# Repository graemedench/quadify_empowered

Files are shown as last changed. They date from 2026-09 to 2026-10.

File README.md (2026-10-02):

# Quadify Empowered

Quadify Empowered is a **post-install enhancement pack** for [Sable](https://github.com/theshepherdmatt/sable) on Volumio. It does not include, replace, or redistribute Sable itself.

## Reversible FM4 conversion

This build is designed to leave the FM4 chassis capable of being returned to its
original FM4 condition. The included mounting and rear-panel parts use existing
openings and fixing points: there is no chassis drilling or cutting. Keep the
original hardware and fasteners with the unit so the conversion can be reversed.

Any work around the original IEC/power hardware must be carried out with the
unit fully disconnected from mains power. Have a suitably competent person make
safe any original mains wiring before removing its outlet or inlet hardware.

## Personal use and original rights

Quadify Empowered is provided for **personal, non-commercial use**. It must not be sold, resold, or commercially redistributed by anyone other than the original Quadify publisher. The original Quadify publisher is expressly permitted to use, distribute, and sell these files commercially. All rights in the original Quadify project and its materials remain with the original Quadify creator and publisher; all rights in Sable remain with its publisher. This enhancement pack does not grant commercial rights in either original project to any other party.

## FM4 button print pack

[`FM4 Button Print Pack`](FM4%20Button%20Print%20Pack/) contains the matching printable button-cap files: an all-variants 3MF plate, individual two-colour FDM parts, editable blank-cap source, and one-piece single-colour resin files with 1 mm raised icons (including a plain resin blank cap). See its read-me for the recommended print workflow.

Install standard Volumio and Sable first. This pack adds reliable OLED/boot feedback, the looping front-panel LED startup pattern, display and audio-performance refinements, improved TIDAL/Sable Radio navigation, configurable radio/TIDAL shortcut buttons, IR support, networking tools, graceful shutdown, and a modern low-overhead display mode.

## Install

This release is verified against Sable commit
`3670e503db8124de5890a6df1dc1b68b95d392a6`. For a repeatable clean build:

```bash
git clone https://github.com/theshepherdmatt/sable.git /home/volumio/sable
cd /home/volumio/sable
git checkout 3670e503db8124de5890a6df1dc1b68b95d392a6
sudo bash install.sh
```

Then install this enhancement pack:

```bash
git clone https://github.com/graemedench/quadify_empowered.git /home/volumio/quadify_empowered
cd /home/volumio/quadify_empowered
sudo ./install.sh
```

The installer checks the Sable revision before it applies anything. If it is not the verified revision, it stops with no changes. For a deliberately attempted newer-version install, take a backup first and use `--force`; it then asks Git to perform a three-way merge and stops on a conflict rather than overwriting code.

## Current front-panel additions

- Button 1: tap play/pause; hold gives the quiet five-minute soft-stop state.
- Button 2 cycles Play Single, Play All, Repeat Single, Repeat All and Shuffle.
- Button 8: tap saves the current item to the TIDAL **Quadify** playlist; hold
  opens Save Shortcut. Press 5, 6 or 7, choose short/long with the encoder,
  then push the encoder to save the current radio/TIDAL source.
- Settings → Shortcuts restores the 5–7 defaults for the selected profile.
- A long encoder press returns directly to Now Playing from any menu/browse depth.
- The panel menu provides display, output, network/IP and emergency Wi-Fi setup.

## CD ripping and library tools

Audio CD offers **Rip HQ** (lossless FLAC) and **Rip MP3** (320kbps), with a choice of internal storage or a mounted USB drive. This uses `cdparanoia`, `cd-discid`, and `ffmpeg` already available on the development Volumio image; other installations need these tools available. Rips are saved under `CD Rips/<artist>/<album>` in a unique folder.

The progress bar follows each track through reading and encoding, alongside a track counter. **Cancel** keeps completed songs; **Exit and continue** returns to the panel while ripping continues. Volumio's library is refreshed after completion or cancellation.

**Settings > Music Library** offers **Refresh now** and automatic refresh: Off, every 15 minutes, or hourly. Automatic refresh defaults to Off on a fresh installation and waits while a CD rip is active. Enable it to pick up files copied over the network.

**Settings > Storage** lists internal storage and mounted USB/network drives with free space. Select a drive for free/total capacity; reopen the list to refresh it.

## Output-menu presets

The default **general** menu detects usable Volumio outputs, hides HDMI, shows the built-in headphone output as variable-volume, and lists external outputs by their detected name.

Graeme's personal menu is restored with:

```bash
sudo ./install.sh --graeme
```

| Menu item | Hardware mapping |
| --- | --- |
| Lineout Fixed | Graeme's SMSL USB DAC, fixed volume |
| Lineout Variable | Graeme's SMSL USB DAC, software volume starting at 50% |
| Headphone Variable | Raspberry Pi built-in Audio Jack, software volume starting at 50% |

No music-service credentials or personal Volumio login details are included.

## Graeme hardware preset

`--graeme` also restores this Pi-specific configuration and backs up `/boot/userconfig.txt` first:

| Function | Configuration |
| --- | --- |
| OLED / panel SPI | `dtparam=spi=on` |
| IR receiver | HS0038 output on BCM GPIO27; 3.3 V and GND; Apple Aluminium Remote profile |
| IR device | `/dev/lirc1` |
| Shutdown button | BCM GPIO21, active-low, controlled by Sable |
| Button 8 | Save current track to Volumio's local `Quadify` playlist |

Reboot after `--graeme` so the IR overlay becomes active. The panel and GPIO wiring must match this profile.

## Updates

```bash
cd /home/volumio/quadify_empowered
git pull
sudo ./install.sh --graeme   # omit the switch for general mode
```

Update standard Sable separately using its own instructions. This remains an add-on, preserving the original project and its licensing.
## Optional playlist backup

To back up the local Volumio `Quadify` playlist (and a clickable, artwork-enabled TIDAL-links page) to your own Windows/NAS SMB share, run:

```bash
cd /home/volumio/quadify_empowered
sudo ./setup-playlist-backup.sh
```

It asks for the server, share, username and password **on the Pi**. None of these values are stored in Git. The credentials are saved only on that Pi in a root-only file. Backups run after every boot and every Sunday at 03:15, retaining `latest` plus three rotating numbered copies.

## Quick Back navigation

Every Settings submenu and music-browsing list ends with **Back**. Select it to return immediately; there is no need to wait for the automatic timeout.

## Shutdown from the panel

At the bottom of **Settings**, choose **Shutdown**, then **Confirm Shutdown**. This uses Sable's graceful shutdown sequence; it stops playback cleanly and turns off the display before power-off.

## Network menu

**Settings → Network** shows the active connection type and network name, for example Wi-Fi: MyNetwork, and can display its current IP address. It also includes an emergency Wi-Fi setup flow: scan for a network, select its SSID, then use the panel control to select password characters. The current password is visible only during entry; JOIN, CANCEL, and DELETE are the first picker options. Joining is passed to Volumio's own network controller, so it remains responsible for saved Wi-Fi settings.

## FM4 wiring diagram

The labelled build diagram is available at [docs/FM4-WIRING-DIAGRAM.svg](docs/FM4-WIRING-DIAGRAM.svg). It records the live FM4 GPIO, I²C, SPI, IR, rotary and shutdown-switch wiring.

The [FM4 build notes](docs/FM4-BUILD-NOTES.md) document the LED-8/IR receiver
conversion and link the included mounting-part STLs.

## Other FM4 printed parts

This repository currently includes the matching button-cap print pack, the
front-panel mounting parts (screen holder, rotary bracket and long knob
extender), and the reversible rear Ethernet-jack panel.

My FM4 build also has additional rear/enclosure pieces, and a cut-out template
for replacing the original PCB. These parts are intentionally **not included
yet** while their fit and final revision are being kept separate from the
current release. A USB-A+C rear-panel option is also planned; it will use the
existing IEC opening and have an optional backing plate to cover the original
power text, again without drilling. These will be added as and when.

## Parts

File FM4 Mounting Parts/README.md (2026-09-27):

# FM4 mounting parts

These are the current printable mounting STL files used on Graeme's FM4.

- `Screen Holder/FM4 Screen Holder V1.stl` — holds the SSD1322 display.
- `Rotary Bracket/FM4 Rotary Knob Bracket V4.stl` — mounts the rotary encoder.
- `Knob Extender/FM4 Knob Extender Long V6.stl` — extends the encoder shaft to
  the front knob.
- [`Rear Network Jack`](Rear%20Network%20Jack/) — a no-drill panel that uses
  the original rear IEC / POWER OUT opening for a panel-mount Ethernet extension.

The Ethernet panel and its fitting photos are documented in its own folder.
Other rear/enclosure parts are still being kept separate while their fit is
finalised.

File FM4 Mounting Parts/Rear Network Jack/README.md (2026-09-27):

# FM4 rear Ethernet jack panel

This STL replaces the original rear IEC / **POWER OUT** outlet with an RJ45
Ethernet extension mounted behind a printed panel. It is a reversible,
no-drill conversion: the panel uses the original rectangular opening and its
existing top and bottom fixing points.

## Included files

- `FM4 Rear Network Jack Panel.stl` — printable adaptor panel.
- `Photo - original IEC outlet.jpg` — the original outlet before removal.
- `Photo - fitted Ethernet panel.jpg` — the fitted RJ45 panel.

## Build reference

**Original IEC / POWER OUT outlet**

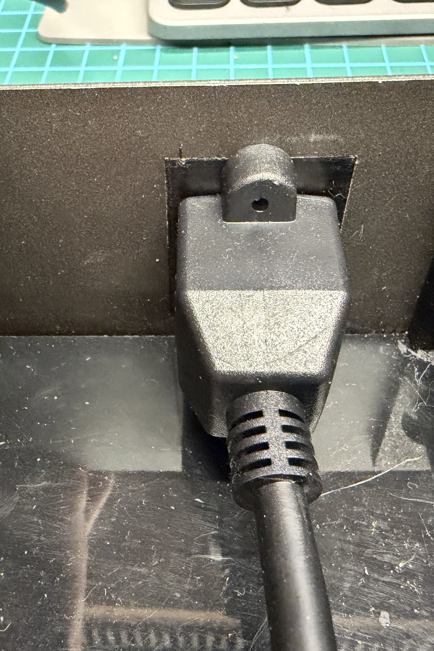
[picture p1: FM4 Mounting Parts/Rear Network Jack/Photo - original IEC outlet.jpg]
Original IEC outlet


**Finished Ethernet panel**

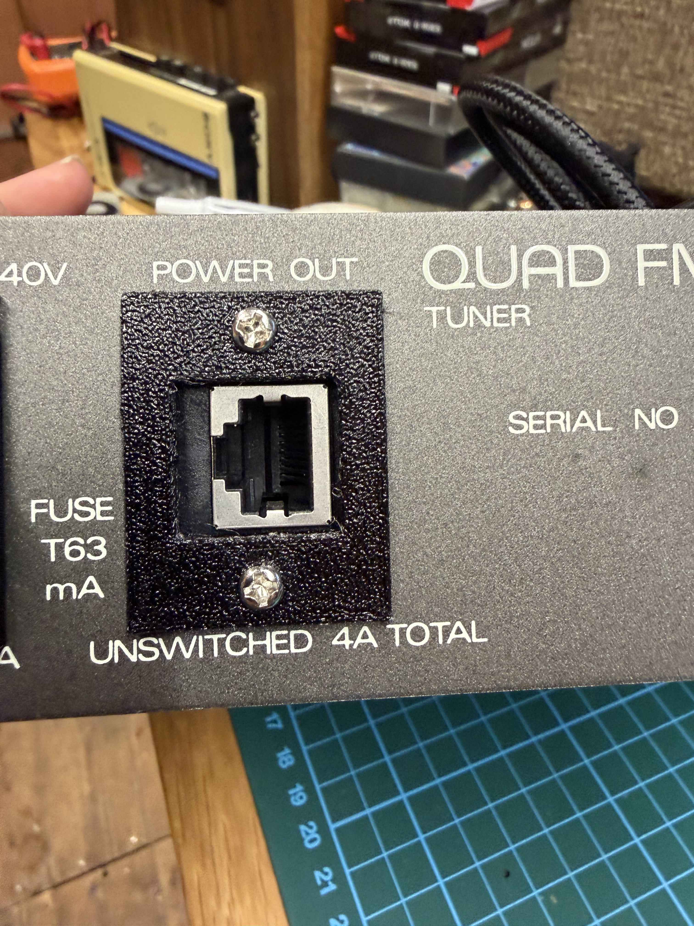
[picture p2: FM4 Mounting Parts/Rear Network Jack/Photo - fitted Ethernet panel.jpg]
Fitted Ethernet panel


## Parts

Use a panel-mount RJ45 female-to-male Ethernet extension that fits this printed
panel, such as the [cable selected for this build](https://www.amazon.co.uk/gp/product/B07QPTTGMF/ref=ox_sc_act_title_1?smid=A3LDV8N4Y4AP0D&psc=1).

## Fitting

1. Disconnect the FM4 completely from mains power.
2. Have a suitably competent person confirm that the original mains hardware
   and wiring are safely isolated before removing the IEC / POWER OUT outlet.
3. Keep the original outlet and its screws in a labelled bag for a future
   return to original FM4 condition.
4. Fit the RJ45 extension to the printed panel, then secure the panel through
   the original top and bottom fixing holes. No drilling or chassis cutting is
   required.
5. Route the Ethernet lead internally without strain, sharp bends or contact
   with power components, then test the network connection before closing the
   chassis.

This is low-voltage network hardware, but its location replaces former mains
equipment. Do not leave any original mains wiring live, loose or exposed.

## Planned companion part

A USB-A+C replacement for the IEC opening is planned. It will also be
no-drill and will include an optional backing plate for covering the original
power text.

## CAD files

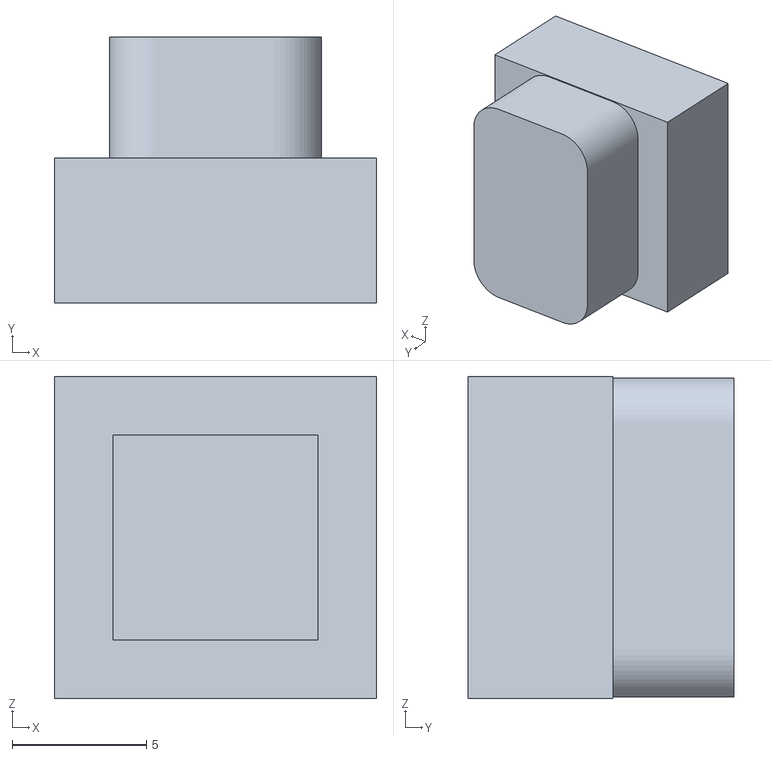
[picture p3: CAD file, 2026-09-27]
FM4 Button Print Pack/Blank Cap/blank button.stl
12.0 x 9.90 x 12.0

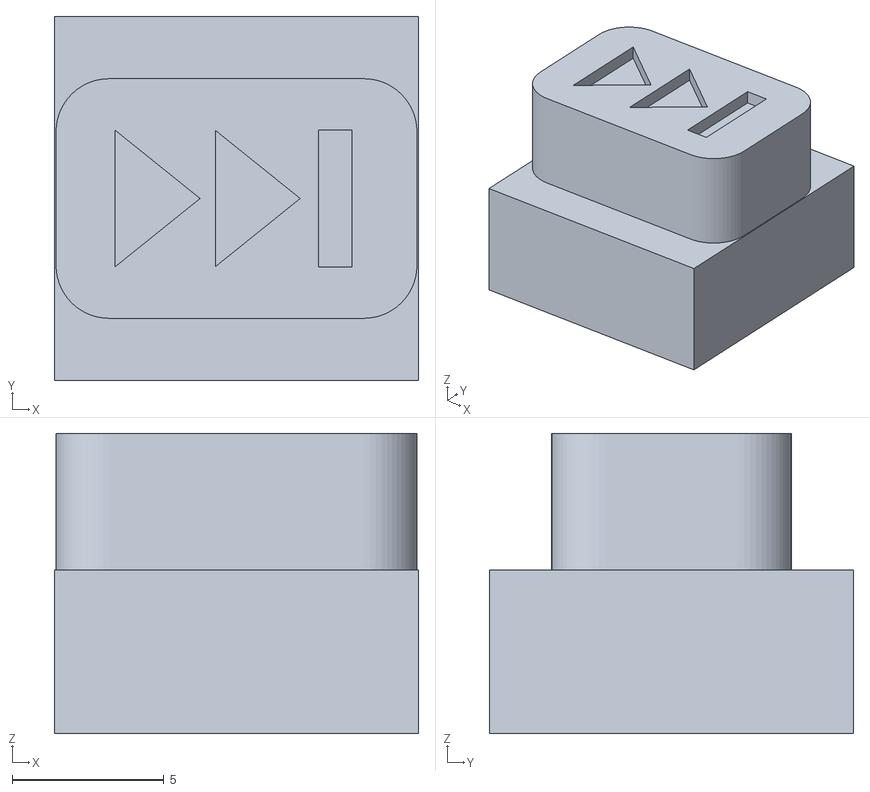
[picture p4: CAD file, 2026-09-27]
FM4 Button Print Pack/Individual STL Files/Skip_forward_-_Flush_Body.stl
12.0 x 12.0 x 9.90

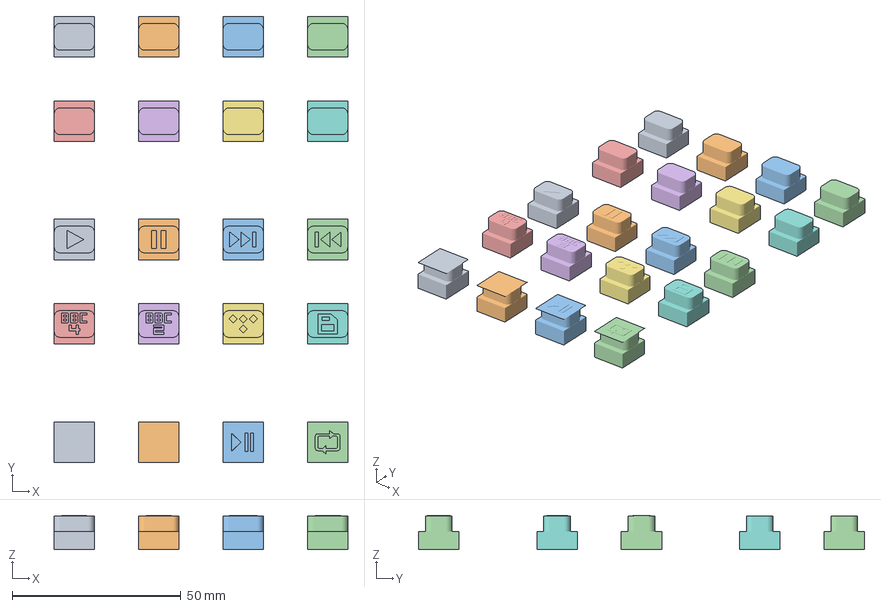
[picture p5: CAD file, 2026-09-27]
FM4 Button Print Pack/Quadify_All_Button_Variants_Face_Up.3mf
87.0 x 132.0 x 10.1 mm
Play - Flush
Pause - Flush
Skip forward - Flush
Skip back - Flush
BBC 4 - Flush
BBC 2 - Flush
TIDAL - Flush
Save - Flush
Play - Raised 0.2mm
Pause - Raised 0.2mm
Skip forward - Raised 0.2mm
Skip back - Raised 0.2mm
BBC 4 - Raised 0.2mm
BBC 2 - Raised 0.2mm
TIDAL - Raised 0.2mm
Save - Raised 0.2mm
Play/Pause - Flush
Play Mode - Flush
Play/Pause - Raised 0.2mm
Play Mode - Raised 0.2mm

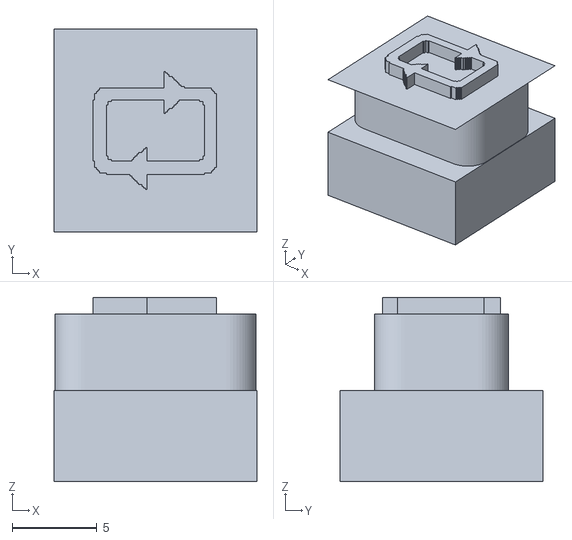
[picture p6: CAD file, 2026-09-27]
FM4 Button Print Pack/Resin - Single Colour Raised 1mm/Play_Mode_-_Resin_Single_Colour_Raised_1mm.stl
12.0 x 12.0 x 10.9

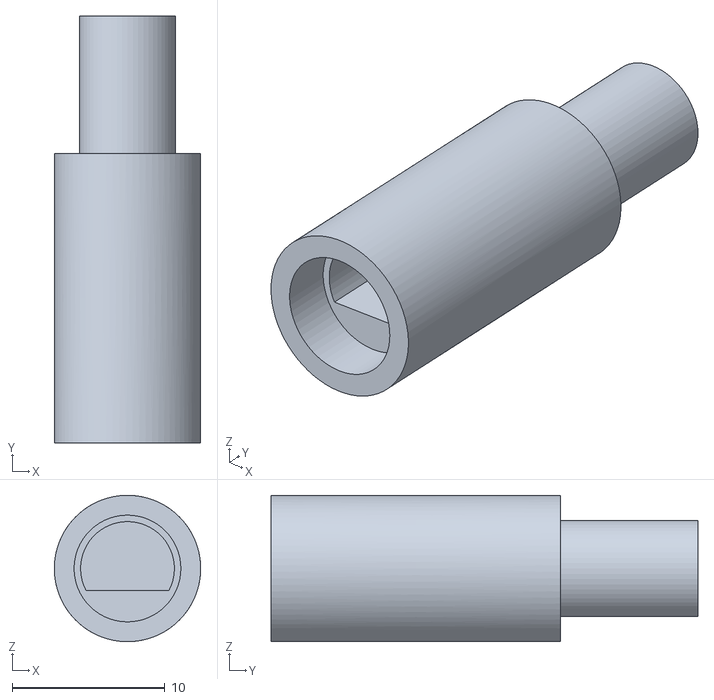
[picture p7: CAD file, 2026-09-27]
FM4 Mounting Parts/Knob Extender/FM4 Knob Extender Long V6.stl
9.60 x 28.0 x 9.60

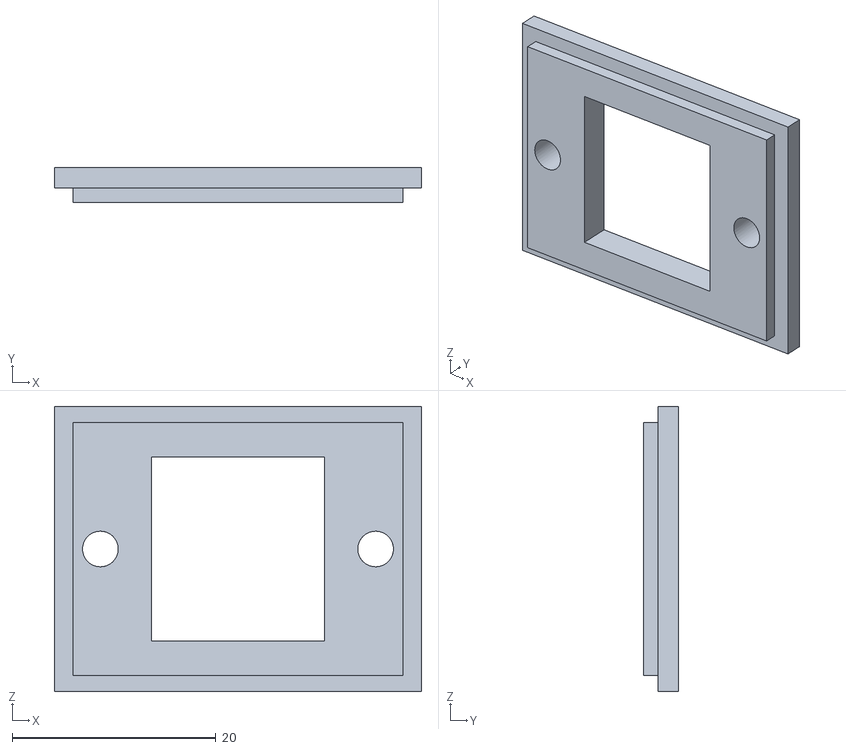
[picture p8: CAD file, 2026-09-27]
FM4 Mounting Parts/Rear Network Jack/FM4 Rear Network Jack Panel.stl
36.0 x 3.40 x 28.0

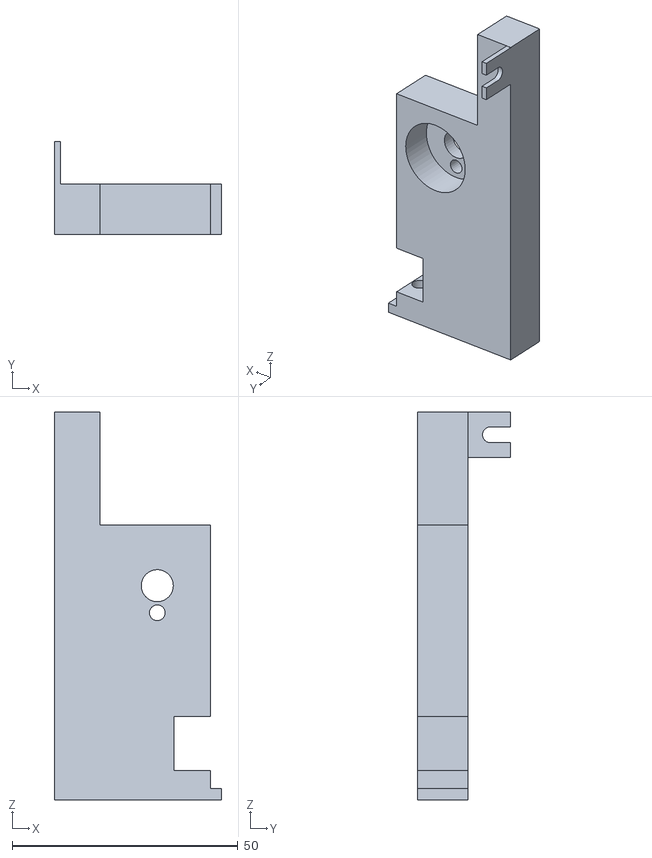
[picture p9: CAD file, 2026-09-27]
FM4 Mounting Parts/Rotary Bracket/FM4 Rotary Knob Bracket V4.stl
37.1 x 20.7 x 86.0

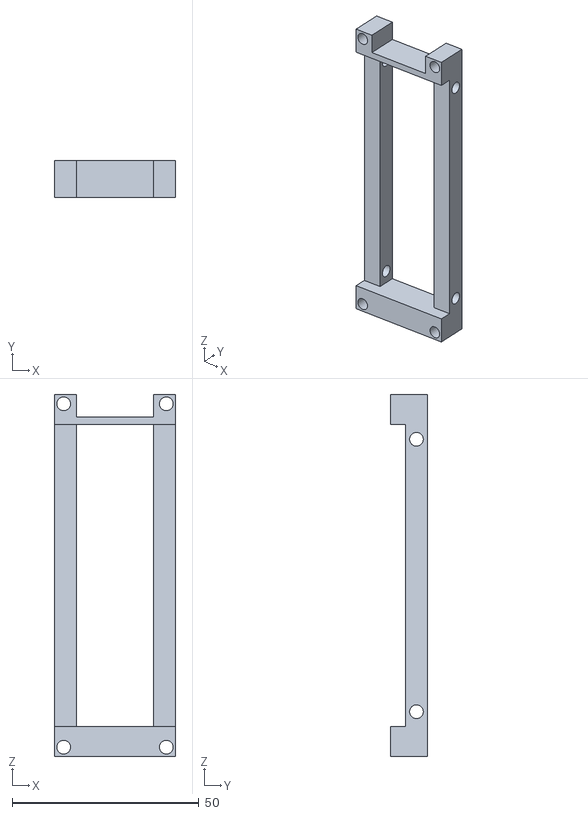
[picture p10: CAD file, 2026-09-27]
FM4 Mounting Parts/Screen Holder/FM4 Screen Holder V1.stl
32.5 x 10.0 x 97.0

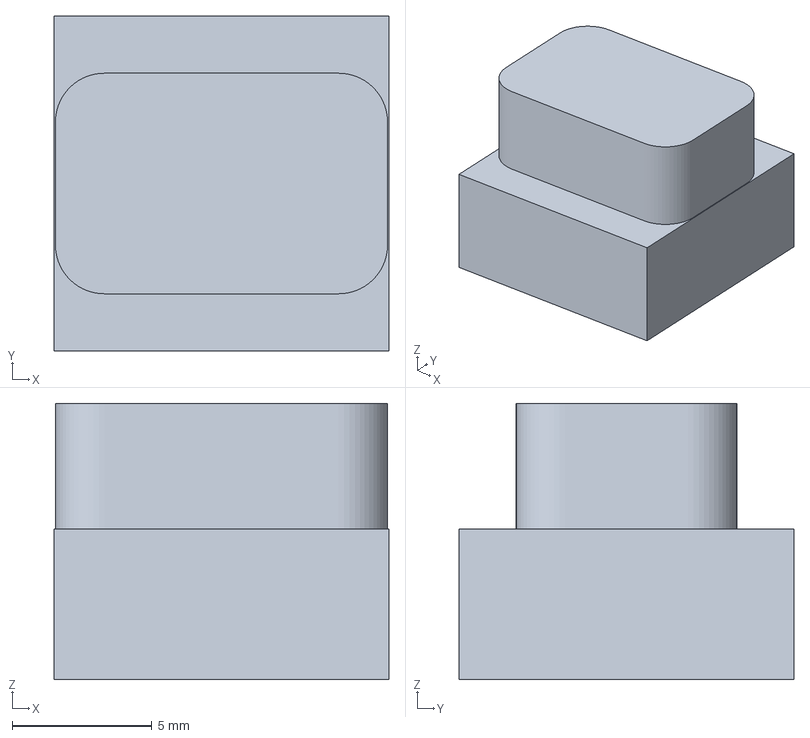
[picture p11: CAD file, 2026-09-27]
FM4 Button Print Pack/Quadify_Blank_Current_Cap.3mf
12.0 x 12.0 x 9.90 mm

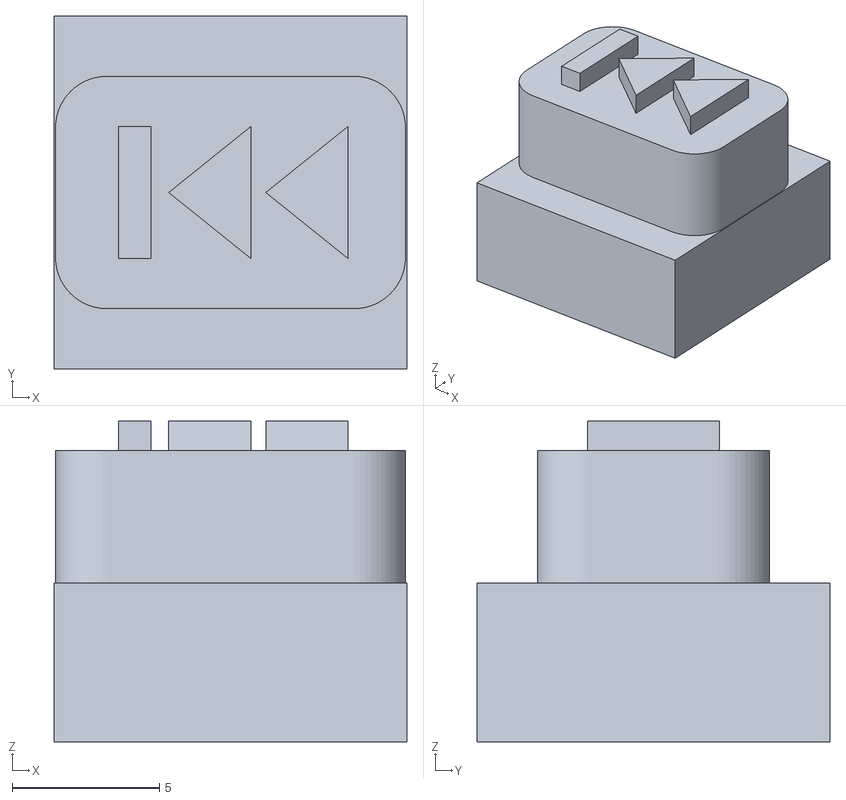
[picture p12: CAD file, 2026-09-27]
FM4 Button Print Pack/Resin - Single Colour Raised 1mm/Skip_back_-_Resin_Single_Colour_Raised_1mm.stl
12.0 x 12.0 x 10.9

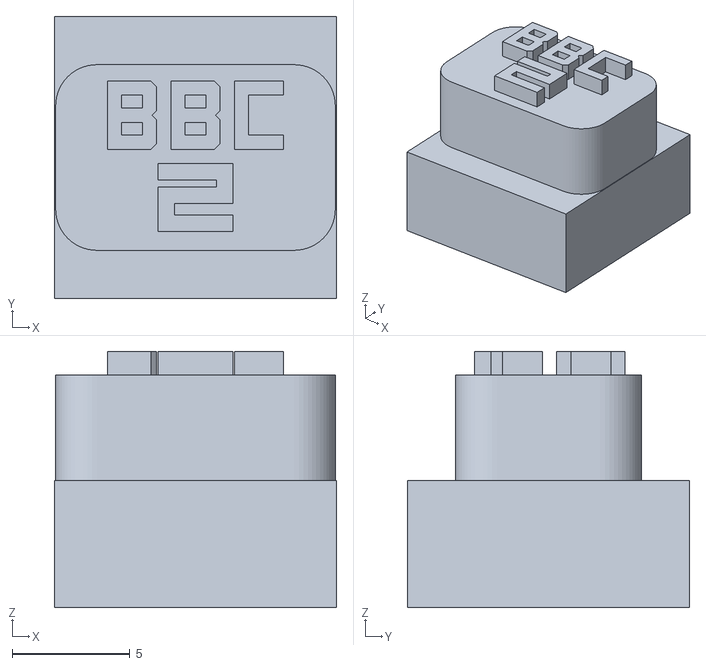
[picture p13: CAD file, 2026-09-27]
FM4 Button Print Pack/Resin - Single Colour Raised 1mm/BBC_2_-_Resin_Single_Colour_Raised_1mm.stl
12.0 x 12.0 x 10.9

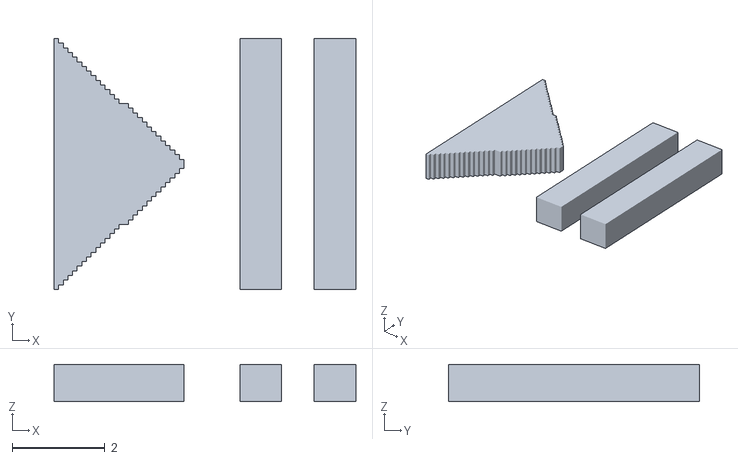
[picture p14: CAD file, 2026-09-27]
FM4 Button Print Pack/Individual STL Files/Play_Pause_-_Raised_0.2mm_White.stl
6.50 x 5.40 x 0.8

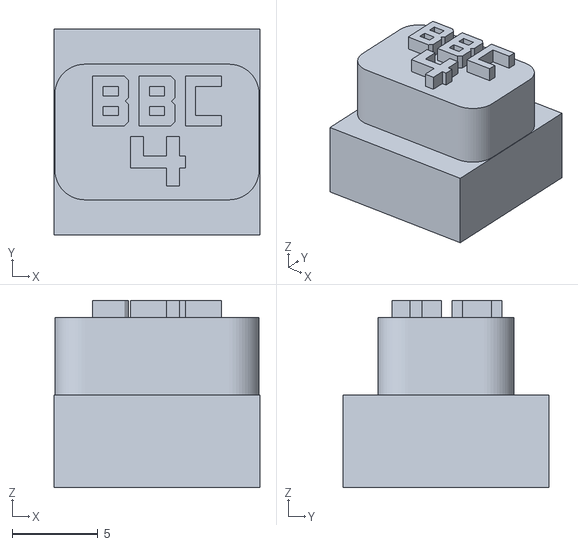
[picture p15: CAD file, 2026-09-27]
FM4 Button Print Pack/Resin - Single Colour Raised 1mm/BBC_4_-_Resin_Single_Colour_Raised_1mm.stl
12.0 x 12.0 x 10.9

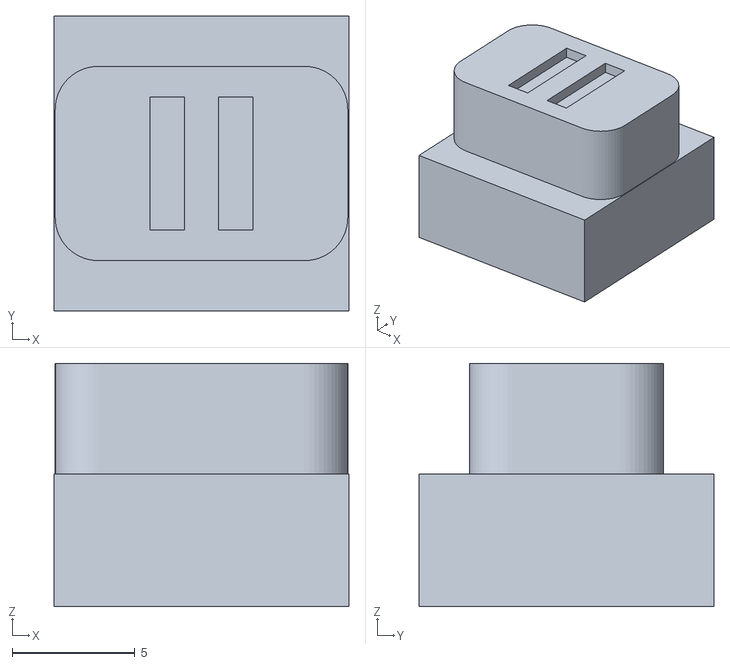
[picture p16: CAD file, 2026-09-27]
FM4 Button Print Pack/Individual STL Files/Pause_-_Flush_Body.stl
12.0 x 12.0 x 9.90

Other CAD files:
FM4 Button Print Pack/Individual STL Files/Skip_back_-_Raised_0.2mm_Body.stl
FM4 Button Print Pack/Resin - Single Colour Raised 1mm/Blank_-_Resin_Single_Colour.stl
FM4 Button Print Pack/Individual STL Files/BBC_2_-_Raised_0.2mm_Body.stl
FM4 Button Print Pack/Blank Cap/blank button.ipt
FM4 Button Print Pack/Individual STL Files/BBC_2_-_Flush_Body.stl
FM4 Button Print Pack/Individual STL Files/BBC_2_-_Flush_White.stl
FM4 Button Print Pack/Individual STL Files/BBC_2_-_Raised_0.2mm_White.stl
FM4 Button Print Pack/Individual STL Files/BBC_4_-_Flush_Body.stl
FM4 Button Print Pack/Individual STL Files/BBC_4_-_Flush_White.stl
FM4 Button Print Pack/Individual STL Files/BBC_4_-_Raised_0.2mm_Body.stl
FM4 Button Print Pack/Individual STL Files/BBC_4_-_Raised_0.2mm_White.stl
FM4 Button Print Pack/Individual STL Files/Pause_-_Flush_White.stl
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

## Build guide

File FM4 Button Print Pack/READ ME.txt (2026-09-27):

QUADIFY FM4 - FINAL PRINT PACK

START HERE

1. Quadify_All_Button_Variants_Face_Up.3mf
   A one-plate chooser containing every original button in both heights plus the four new revised choices. Remove unwanted caps in Creality Print, then slice.

2. All_Button_Variants_Preview.png
   A visual guide to every selectable cap in the all-variants project.

3. Quadify_Blank_Current_Cap.3mf
   One current-generation blank cap, centred on its own plate and printed entirely with filament 3.

INDIVIDUAL PARTS

4. Individual STL Files\
   All individual cap parts are together in one folder. Every regular cap is a Body + White pair: Body = filament 3 (dark); White = filament 2 (white).
   The revised Play/Pause and Play Mode caps are included in both Flush and Raised 0.2 mm versions in the same format. The two *_White_Overlay files are retained only for advanced custom projects; use the matching Body + White files for normal printing.

5. Resin - Single Colour Raised 1mm\
   Ten one-piece resin-printing button STL files. Each is a single colour with its icon raised 1 mm above the cap face; no separate body or white part is needed. Blank_-_Resin_Single_Colour.stl is the matching plain no-icon cap.

6. Blank Cap\blank button.ipt
   The supplied blank Inventor source and STL, retained for design work. It is an earlier blank-cap source; use Quadify_Blank_Current_Cap.3mf when printing a current fitted blank cap.

Re-slice each project in Creality Print before printing. Development and earlier button sets remain outside this final-pack folder.

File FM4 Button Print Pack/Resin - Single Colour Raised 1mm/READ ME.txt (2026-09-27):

QUADIFY FM4 - RESIN SINGLE-COLOUR BUTTONS

Each STL in this folder is one single-colour cap, ready to import into a resin slicer. The icon stands 1 mm above the cap face for a clear tactile result. There are no separate body or white parts to assemble. Blank_-_Resin_Single_Colour.stl is the plain, no-icon version.

Use the FDM Body + White files in the parent folder for the two-colour versions.

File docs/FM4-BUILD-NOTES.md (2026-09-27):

# FM4 build notes

## Front-panel IR conversion

The original **LED 8** position is reused as the visible opening for the
HS0038 IR receiver.

- LED 8 is **not disconnected**: its MCP23017 connection remains intact.
- The LED itself is pulled back behind the front panel so it does not occupy
  the opening or shine directly through the receiver position.
- The HS0038 receiver is mounted in the old LED-8 opening, with its OUT pin on
  Raspberry Pi GPIO27 (physical pin 13), VCC on 3.3 V and GND on ground.

This keeps the eight-channel LED hardware reversible while giving the IR sensor
a neat, front-facing location.

## Rear Ethernet jack conversion

[`Rear Network Jack`](../FM4%20Mounting%20Parts/Rear%20Network%20Jack/) holds a
panel-mount Ethernet extension in the original rear IEC / **POWER OUT** opening.
It uses the original opening and fixing points, so no drilling or cutting is
required.

With the unit disconnected from mains power, have any original mains wiring
made safe by a suitably competent person before removing the original IEC
hardware. Retain the original outlet/inlet hardware and screws if the FM4 may
later be returned to its original condition.

## Included mounting parts

The current printable mounting parts are in
[`FM4 Mounting Parts`](../FM4%20Mounting%20Parts/): screen holder, rotary-knob
bracket, knob extender and the rear Ethernet-jack panel.

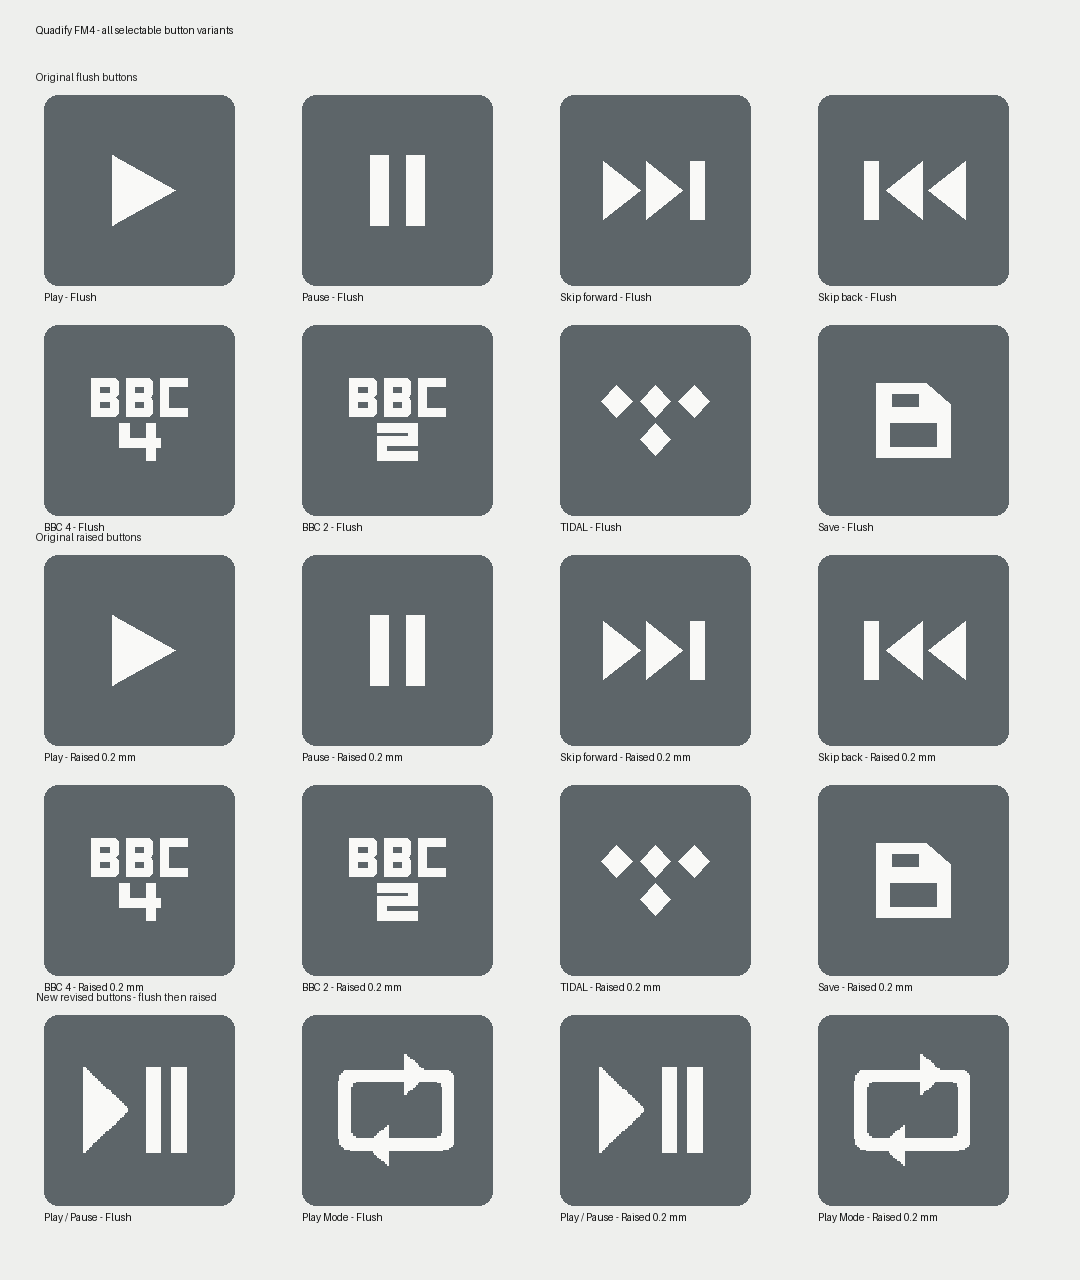
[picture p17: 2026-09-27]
FM4 Button Print Pack/All_Button_Variants_Preview.png

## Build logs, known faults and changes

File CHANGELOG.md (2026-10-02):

# Changelog

## 2026-10-03

- Added Audio CD browsing with a distinct disc icon and HQ FLAC / 320kbps MP3 ripping to internal storage or mounted USB drives.
- Added per-track reading/encoding progress, the track counter, Cancel, and Exit and continue; the rip screen stays awake.
- Corrected storage alias handling and ripped-album permissions so Volumio can index and play completed files.
- Added Settings > Music Library with manual and configurable automatic refresh, and Settings > Storage with free/total space.
- Improved clock readiness detection and CD menu recovery after slow startup or reconnects.
- Verified the generated patch on the clean supported Sable base, with 33 focused checks passing, including real FLAC/MP3 encoding.

## 2026-10-01

- Hardened the installer against executable-bit changes made by Volumio's Sable plugin deployment.
- Rebuilt the Sable enhancement patch from a verified clean base and added a clean-apply verification step to the release process.
- The installer now rebuilds and refreshes Sable's Volumio settings-page payload automatically.
- Fixed playlist-backup setup for server or share names containing spaces.

## 2026-09-27

- Added the no-drill, reversible rear Ethernet-jack panel STL, fitting photos
  and safety-first fitting notes for the original IEC / POWER OUT opening.
- Documented the reversible FM4-conversion principle and the planned USB-A+C
  rear-panel option with optional power-text backing plate.
- Regenerated the Sable enhancement patch from the full current FM4 build.
- Added the looping boot LED animation, playback-mode display refinements,
  audio-first display settling and soft-stop behaviour.
- Added button 5–7 short/long shortcut learning: hold Save (8), press a target
  button, choose short/long with the encoder, then confirm with the encoder.
- Added Settings → Shortcuts → Reset 5–7 Defaults.
- A long encoder press now exits directly to Now Playing from menu/browse depth.
- Added a fully documented `--graeme` preset with the current button, display,
  audio and Apple IR defaults.
- The installer now identifies the verified Sable base and supports an explicit
  `--force` three-way-merge attempt for other versions.

## 2026-09-26

- Added **Settings → Shutdown** at the bottom of the Settings menu, with a confirmation step before the existing graceful shutdown routine runs.
- Added a **Back** item at the bottom of Settings and all music-browsing lists, for immediate return without waiting for the timeout.

## 2026-09-22

- Added a Network panel menu with live connection type, network name and IP-address display.
- Added Wi-Fi scanning and an emergency on-screen password picker: rotate to choose a character, press to add it; JOIN, CANCEL and DELETE are at the start of the picker.
- Wi-Fi joining is delegated to Volumio's network controller.
- Added the minimum permission needed for the Sable service to scan Wi-Fi.

## Earlier releases

- Display, boot feedback, TIDAL/Sable Radio navigation, IR controls, audio-output modes and Button 8 save-track enhancements.
- Optional network-share backup of the local Quadify playlist and its artwork-enabled TIDAL links page.

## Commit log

2026-09-27 Add FM4 button print pack
    [BBC_2_-_Flush_Body.stl, BBC_2_-_Flush_White.stl, BBC_2_-_Raised_0.2mm_Body.stl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]
2026-09-27 Add FM4 wiring diagram
2026-09-27 Document IR front-panel conversion and add mounting STLs
    [FM4 Knob Extender Long V6.stl, FM4 Rotary Knob Bracket V4.stl, FM4 Screen Holder V1.stl]
2026-09-27 Document additional FM4 printed parts
2026-09-27 Refine FM4 printed parts note
2026-09-27 Add reversible FM4 rear Ethernet panel
    [FM4 Rear Network Jack Panel.stl]
2026-09-27 Add FM4 PCB replacement laser template
    [FM4 PCB Replacement Panel - Rev A.dxf]
2026-09-27 Remove unverified PCB template
    [FM4 PCB Replacement Panel - Rev A.dxf]
